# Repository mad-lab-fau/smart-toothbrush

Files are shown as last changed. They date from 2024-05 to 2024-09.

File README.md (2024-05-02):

# Smart Toothbrush 

Screenshot (1012)

# Overview 
The smart toothbrush is a custom microcontroller board that is built around an **ESP32 processor**. It contains an **Inertial Measurement Unit (IMU)** for tracking linear accelerations with an accelerometer and rotational velocities with a gyroscope. Additionally, a **Real-Time Clock (RTC)** unit is used for timekeeping. The data is written onto a **MircoSD card**. All these components are mounted on a Printed Circuit Board (PCB), providing a compact and efficient design. The electronics are protected from environmental influences by a customised outer case in the shape of a toothbrush. The result is a smart toothbrush with replaceable brushes that can be used for normal tooth brushing.

# Documentation: [Wiki](https://github.com/mad-lab-fau/smart-toothbrush/wiki) 
[Project Overview](https://github.com/mad-lab-fau/smart-toothbrush/wiki/Project-Overview) <br> 
[Hardware-Guide](https://github.com/mad-lab-fau/smart-toothbrush/wiki/Hardware-Guide) <br>
[Software-Guide](https://github.com/mad-lab-fau/smart-toothbrush/wiki/Software-Guide) <br>
[User Manual](https://github.com/mad-lab-fau/smart-toothbrush/wiki/User-Manual)<br>
[Open Issues and Enhancement Opportunities](https://github.com/mad-lab-fau/smart-toothbrush/wiki/Open-Issues-and-Enhancement-Opportunities)<br>

# Studies Using the Smart Toothbrush
The following papers used the Smart Toothbrush in their research:
- *further papers to be added - let us know if you used the Smart Toothbrush in your research!*

# Contributing
We welcome contributions to the Smart Toothbrush project! To contribute, please fork this repository and submit a pull request with your changes. If you run into any issues or have any questions, please open an [issue on Github](https://github.com/mad-lab-fau/smart-toothbrush/issues). If you are using the Smart Toothbrush in your research or project, we would love to hear about it and link your work here!

# License
The Smart Toothbrush is licensed under the MIT License. See the LICENSE file for more information.

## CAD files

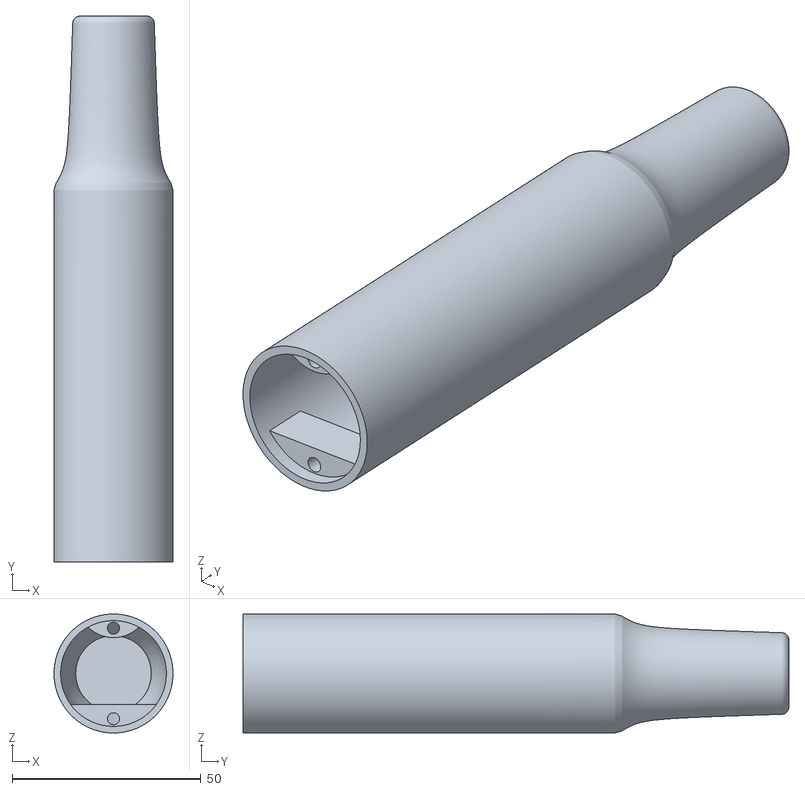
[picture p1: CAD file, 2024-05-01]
hardware/CAD_components/STL_files/outer_shell.stl
31.5 x 144.5 x 31.5

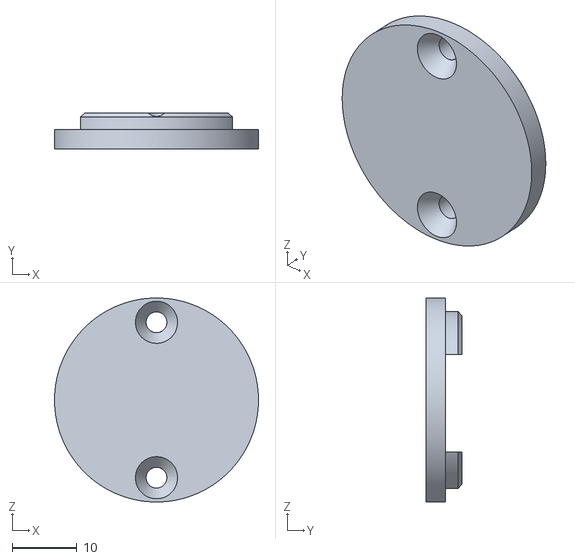
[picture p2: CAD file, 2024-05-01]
hardware/CAD_components/STL_files/cover.stl
31.5 x 5.50 x 31.5

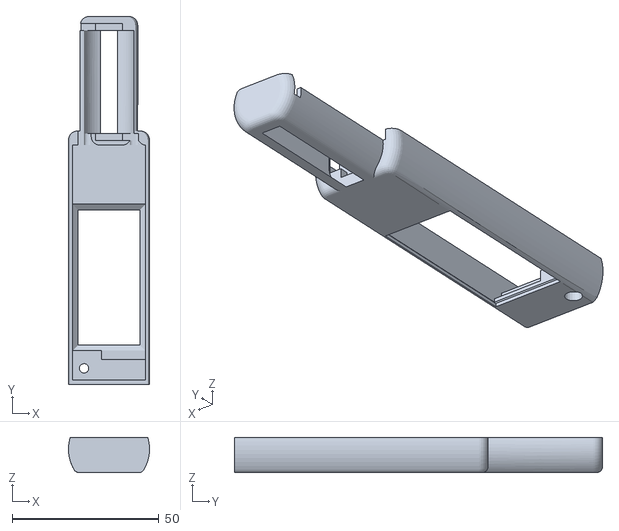
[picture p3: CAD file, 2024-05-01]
hardware/CAD_components/STL_files/inner_case.stl
27.6 x 125.3 x 12.0

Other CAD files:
hardware/CAD_components/Fusion360_designs/cover.f3d
hardware/CAD_components/Fusion360_designs/inner_case.f3d
hardware/CAD_components/Fusion360_designs/outer_shell.f3d

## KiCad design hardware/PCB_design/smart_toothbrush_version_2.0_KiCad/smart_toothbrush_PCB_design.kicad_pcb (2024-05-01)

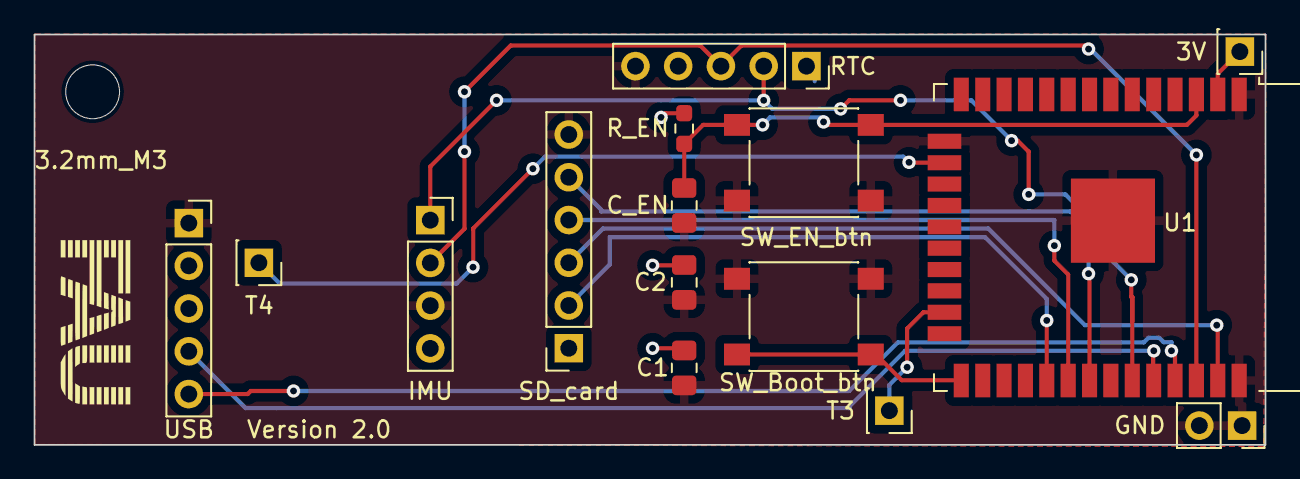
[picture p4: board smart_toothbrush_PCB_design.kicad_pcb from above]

Board: 2 copper layers, 73.2 x 24.4 mm, 16 parts (0 on the bottom side), 14 nets.

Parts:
3.2mm_M3: MountingHole_3.2mm_M3
3V: Conn_01x01_Male; PinSocket_1x01_P2.54mm_Vertical
C1: 10uF; C_0805_2012Metric_Pad1.18x1.45mm_HandSolder
C2: 0.1uF; C_0805_2012Metric_Pad1.18x1.45mm_HandSolder
C_EN: 0.1uF; C_0805_2012Metric_Pad1.18x1.45mm_HandSolder
GND: Conn_01x02_Pin; PinSocket_1x02_P2.54mm_Vertical
IMU: Conn_01x04_Male; PinSocket_1x04_P2.54mm_Vertical
RTC: Conn_01x05_Male; PinSocket_1x05_P2.54mm_Vertical
R_EN: 10K; R_0603_1608Metric_Pad0.98x0.95mm_HandSolder
SD_card: Conn_01x06_Male; PinSocket_1x06_P2.54mm_Vertical
SW_Boot_btn: SW_Push; SW_Push_1P1T_NO_6x6mm_H9.5mm
SW_EN_btn: SW_Push; SW_Push_1P1T_NO_6x6mm_H9.5mm
T3, T4: Conn_01x01_Male; PinSocket_1x01_P2.54mm_Vertical
U1: ESP32-WROOM-32
USB: Conn_01x05_Male; PinSocket_1x05_P2.54mm_Vertical

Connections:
+3V3: 3V.1, C1.1, C2.1, IMU.4, RTC.1, R_EN.1, SD_card.1, U1.2 (VDD), USB.3
/EN: C_EN.1, R_EN.2, SW_EN_btn.2, U1.3 (EN)
/IO0: SW_Boot_btn.2, U1.25 (IO0)
/IO5: SD_card.2, U1.29 (IO5)
/IO18: SD_card.4, U1.30 (IO18)
/IO19: SD_card.5, U1.31 (IO19)
/IO21: IMU.1, RTC.2, U1.33 (IO21)
/IO22: IMU.2, RTC.3, U1.36 (IO22)
/IO23: SD_card.3, U1.37 (IO23)
/RXD0: U1.34 (RXD0/IO3), USB.4
/T3: T3.1, U1.23 (IO15)
/T4: T4.1, U1.16 (IO13)
/TXD0: U1.35 (TXD0/IO1), USB.5
GND: C1.2, C2.2, C_EN.2, GND.1, GND.2, IMU.3, RTC.5, SD_card.6, SW_Boot_btn.1, SW_EN_btn.1, U1.1 (GND), U1.15 (GND), U1.38 (GND), U1.39 (GND), USB.1

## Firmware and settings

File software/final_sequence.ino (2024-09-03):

//import nessecary libraries
#include "SparkFunLSM6DS3.h"
#include "Wire.h"
#include "SPI.h"
#include "FS.h"
#include "SD.h"

#include "RTClib.h"
#include <Preferences.h>
Preferences preferences;

//initialize I2C devices
RTC_DS3231 rtc;
LSM6DS3 myIMU(I2C_MODE, 0x6B);

//RTC variables written in Flash memory
RTC_DATA_ATTR int booter = 0;
RTC_DATA_ATTR int reseter = 0;
char fileName[10];
RTC_DATA_ATTR int saver = 0;

uint8_t int1Status = 0;
volatile bool activity_flag = true;
volatile bool reset_once = false;
uint8_t latched = 0;

//timer for reseting the motion flag
hw_timer_t * timer = NULL;
portMUX_TYPE timerMux = portMUX_INITIALIZER_UNLOCKED;




void setup( void ) {
  //Over-ride default settings if desired
  myIMU.settings.gyroEnabled = 1;  //Can be 0 or 1
  myIMU.settings.gyroRange = 2000;   //Max deg/s.  Can be: 125, 245, 500, 1000, 2000
  myIMU.settings.gyroSampleRate = 833;   //Hz.  Can be: 13, 26, 52, 104, 208, 416, 833, 1666
  myIMU.settings.gyroBandWidth = 200;  //Hz.  Can be: 50, 100, 200, 400;
  myIMU.settings.gyroFifoEnabled = 1;  //Set to include gyro in FIFO
  myIMU.settings.gyroFifoDecimation = 1;  //set 1 for on /1

  myIMU.settings.accelEnabled = 1;
  myIMU.settings.accelRange = 16;      //Max G force readable.  Can be: 2, 4, 8, 16
  myIMU.settings.accelSampleRate = 833;  //Hz.  Can be: 13, 26, 52, 104, 208, 416, 833, 1666, 3332, 6664, 13330
  myIMU.settings.accelBandWidth = 200;  //Hz.  Can be: 50, 100, 200, 400;
  myIMU.settings.accelFifoEnabled = 1;  //Set to include accelerometer in the FIFO
  myIMU.settings.accelFifoDecimation = 1;  //set 1 for on /1
  myIMU.settings.tempEnabled = 1;
  
    //Non-basic mode settings
  myIMU.settings.commMode = 1;

  //FIFO control settings
  myIMU.settings.fifoThreshold = 1200;  //Can be 0 to 4096 (16 bit bytes)
  myIMU.settings.fifoSampleRate = 200;  //Hz.  Can be: 10, 25, 50, 100, 200, 400, 800, 1600, 3300, 6600
  myIMU.settings.fifoModeWord = 6;  //FIFO mode.

  //  //Error accumulation variable
  uint8_t errorAccumulator = 0;
  uint16_t errorsAndWarnings = 0;
  uint8_t dataToWrite = 0;  //Temporary variable



  Serial.begin(115200);  // start serial for output
  delay(100); //relax...
  Serial.println("Processor came out of reset.\n");

     //get current boot number
     preferences.begin("my-app", false);
     unsigned int counter = preferences.getUInt("counter", 0);
     counter++;
     booter = counter;
     Serial.printf("Current counter value: %u\n", counter); 
     Serial.printf("Current booter value: %u\n", booter); 
     Serial.printf("Current reseter value: %u\n", reseter);
     preferences.putUInt("counter", counter);                   // Store the counter to the Preferences
     preferences.end();                                         // Close the Preferences

//start RTC
  if (! rtc.begin()) {
    Serial.println("Couldn't find RTC");
    }

//set time to the time when the code was uploaded, if it is the first boot
 if(booter == 1 ){
  rtc.adjust(DateTime(F(__DATE__), F(__TIME__)));
  }
    

setupSDCard();
setupIMU();

  //start timer for resetting the motion flag
  timer = timerBegin(0, 80, true);
  timerAttachInterrupt(timer, &reset_activity, true);
  timerAlarmWrite(timer, 5000000, true); //105-210 sec test/  reset activity every 10seconds (double the time because  activiy flag has to be false)
  timerAlarmEnable(timer);

        //set respective register while logging
          myIMU.writeRegister( LSM6DS3_ACC_GYRO_TAP_CFG1, 0x91 );         //if who_am_i=106
        //  myIMU.writeRegister( LSM6DS3_ACC_GYRO_TAP_CFG1, 0x01 );         //if who_am_i=105
          myIMU.writeRegister( LSM6DS3_ACC_GYRO_WAKE_UP_DUR, 0x00 );
          myIMU.writeRegister( LSM6DS3_ACC_GYRO_WAKE_UP_THS, 0x01 );
          myIMU.writeRegister( LSM6DS3_ACC_GYRO_MD1_CFG, 0x20 );
          attachInterrupt(digitalPinToInterrupt(13), int1ISR, RISING); 

}


void setupSDCard(){
  if(!SD.begin()){
      return;
  }
  uint8_t cardType = SD.cardType();
  if(cardType == CARD_NONE){
      return;
  }

}

void setupIMU(){
  Wire.begin();
  Wire.setClock(800000L);
  
        if( myIMU.begin() != 0 ){
          Serial.println("Problem starting the sensor");
          Serial.println(myIMU.begin());
          }
        else{
          Serial.println("IMU started.");
          }
          
        uint8_t dataToWrite = 0;                                          //Temporary variable
        myIMU.readRegister(&dataToWrite, LSM6DS3_ACC_GYRO_WHO_AM_I_REG);  //Read out version of LSM6ds3 from "WHO_AM_I" register
        Serial.println(dataToWrite);                                      //Print version - 106=LSM6ds3-c; 105=LSM6ds3

        
        Serial.println("Configuring FIFO");
        myIMU.fifoBegin();
        Serial.println("fifo Begin done");
        
        Serial.println("Clearing out the FIFO...");
        myIMU.fifoClear();
        Serial.println("Fifo clear");
        }


void int1ISR() //sets and resets the activity flag
{
  int1Status++;
  activity_flag = true;
  reset_once = false;
}

void reset_activity(){ //everytime the timer is finished, activity flag gets set to false
  if(reset_once == true){
  activity_flag = false;
  }
  reset_once = true;
}



void loop(){
          float temp;  //This is to hold read data
          uint16_t tempUnsigned;

  //get the current time        
  DateTime now = rtc.now();
  int day=now.day();int month=now.month(); int year=now.year();int hour=now.hour();int minute=now.minute();int second=now.second();
   
    //create file with boot number as name
    snprintf(fileName, 9, "/%03d.txt", booter);
    File file = SD.open(fileName ,FILE_APPEND); 
    
    file.print(reseter);file.print(". Reset_boot, ");file.print(booter);file.print(". Boot:\n"); 
    file.print("Recording started at:\n"); 
    file.print(day);file.print(".");file.print(month);file.print(".");file.print(year);file.print(" - ");
    file.print(hour);file.print(":");file.print(minute);file.print(","); file.print(second);file.print("\n ");
    file.print("Gx;Gy;Gz;X;Y;Z\n");  
    file.close();




       int counter = millis();
      // digitalWrite(15, HIGH); //if LED is connected to T3
       
       while(activity_flag == true){
        
          myIMU.fifoClear(); 
          while( ( myIMU.fifoGetStatus() & 0x8000 ) == 0 ) {};  //Wait for watermark that FIFO is full
          File file = SD.open(fileName ,FILE_APPEND);
          
          while( ( myIMU.fifoGetStatus() & 0x1000 ) == 0 ) {   //empty FIFO        
 
                temp = myIMU.calcGyro(myIMU.fifoRead());
                file.print(temp);file.print(";");
                
                temp = myIMU.calcGyro(myIMU.fifoRead());
                file.print(temp);file.print(";");

                temp = myIMU.calcGyro(myIMU.fifoRead());
                file.print(temp);file.print(";");
                
                temp = myIMU.calcAccel(myIMU.fifoRead());
                file.print(temp);file.print(";");
                
                temp = myIMU.calcAccel(myIMU.fifoRead());
                file.print(temp);file.print(";");

                temp = myIMU.calcAccel(myIMU.fifoRead()); 
                file.print(temp);file.print("\n ");
          
          }
        
          tempUnsigned = myIMU.fifoGetStatus();
          Serial.print("Outside of Fifo");
          Serial.print("\n");  
          myIMU.readRegister(&latched, LSM6DS3_ACC_GYRO_WAKE_UP_SRC);
       }
                  
                    
myIMU.fifoClear();
myIMU.fifoEnd();

file.close();
Serial.println("Going to sleep");
SD.end();

//settings to configure IMU for wake up interrupts
          timerWrite(timer, 0);
          digitalWrite(15, LOW);
          myIMU.writeRegister( LSM6DS3_ACC_GYRO_TAP_CFG1, 0x90 );         //if who_am_i=106 -> LSM6ds3-c
          //myIMU.writeRegister( LSM6DS3_ACC_GYRO_TAP_CFG1, 0x00 );         //if who_am_i=105 -> LSM6ds3
          myIMU.writeRegister( LSM6DS3_ACC_GYRO_WAKE_UP_DUR, 0x00 );
          myIMU.writeRegister( LSM6DS3_ACC_GYRO_WAKE_UP_THS, 0x01 );
          myIMU.writeRegister( LSM6DS3_ACC_GYRO_MD1_CFG, 0x20 );
          attachInterrupt(digitalPinToInterrupt(13), int1ISR, RISING);     // interrupt to wake the ESP32 when the toothbrush is used
          reseter++;
  esp_sleep_enable_ext0_wakeup(GPIO_NUM_13,1);
  esp_deep_sleep_start();
  
                    
}

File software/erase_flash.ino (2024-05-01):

#include <Preferences.h>

Preferences preferences;

void setup() {
  Serial.begin(115200);
  Serial.println();

  // Open Preferences with my-app namespace. Each application module, library, etc
  // has to use a namespace name to prevent key name collisions. We will open storage in
  // RW-mode (second parameter has to be false).
  // Note: Namespace name is limited to 15 chars.
  preferences.begin("my-app", false);

  // Remove all preferences under the opened namespace
  preferences.clear();

  // Or remove the counter key only
  //preferences.remove("counter");

  // Get the counter value, if the key does not exist, return a default value of 0
  // Note: Key name is limited to 15 chars.
  unsigned int counter = preferences.getUInt("counter", 0);

  // Increase counter by 1
  //counter++;

  // Print the counter to Serial Monitor
  Serial.printf("Current counter value: %u\n", counter);

  // Store the counter to the Preferences
  preferences.putUInt("counter", counter);

  // Close the Preferences
  preferences.end();

  // Wait 10 seconds
  Serial.println("Restarting in 10 seconds...");
  delay(10000);

  // Restart ESP
  ESP.restart();
}

void loop() {}

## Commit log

2024-05-01 Added all project files
    [cover.f3d, cover.stl, inner_case.f3d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]
2024-09-03 Fixed bug: Wrong conversion of the gyroscope values
    [final_sequence.ino]
